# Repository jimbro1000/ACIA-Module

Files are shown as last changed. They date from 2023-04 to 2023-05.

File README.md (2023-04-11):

# HD6309SBC ACIA MODULE #

This design provides a standard RS232 capability to the
HD6309SBC board. Available baud rates range from 50 to
115200.

## Interface ##

The board utilises mapped IO at address #xx0C to interact
with the primary processor. The R65C51 uart provides four
registers starting at this address.

The value of xx depends on the "mapped memory" signal line,
by default this is $FF00.

## Notes ##

The intended clock speed of the main SBC board is just over
3MHz which exceeds the limits of the original R65C51.
A slower clock speed would facilitate the use of the Rockwell
made components but it is highly recommended to use the WDC
version which will operate at much higher clock frequencies
(higher than the main clock can supply)

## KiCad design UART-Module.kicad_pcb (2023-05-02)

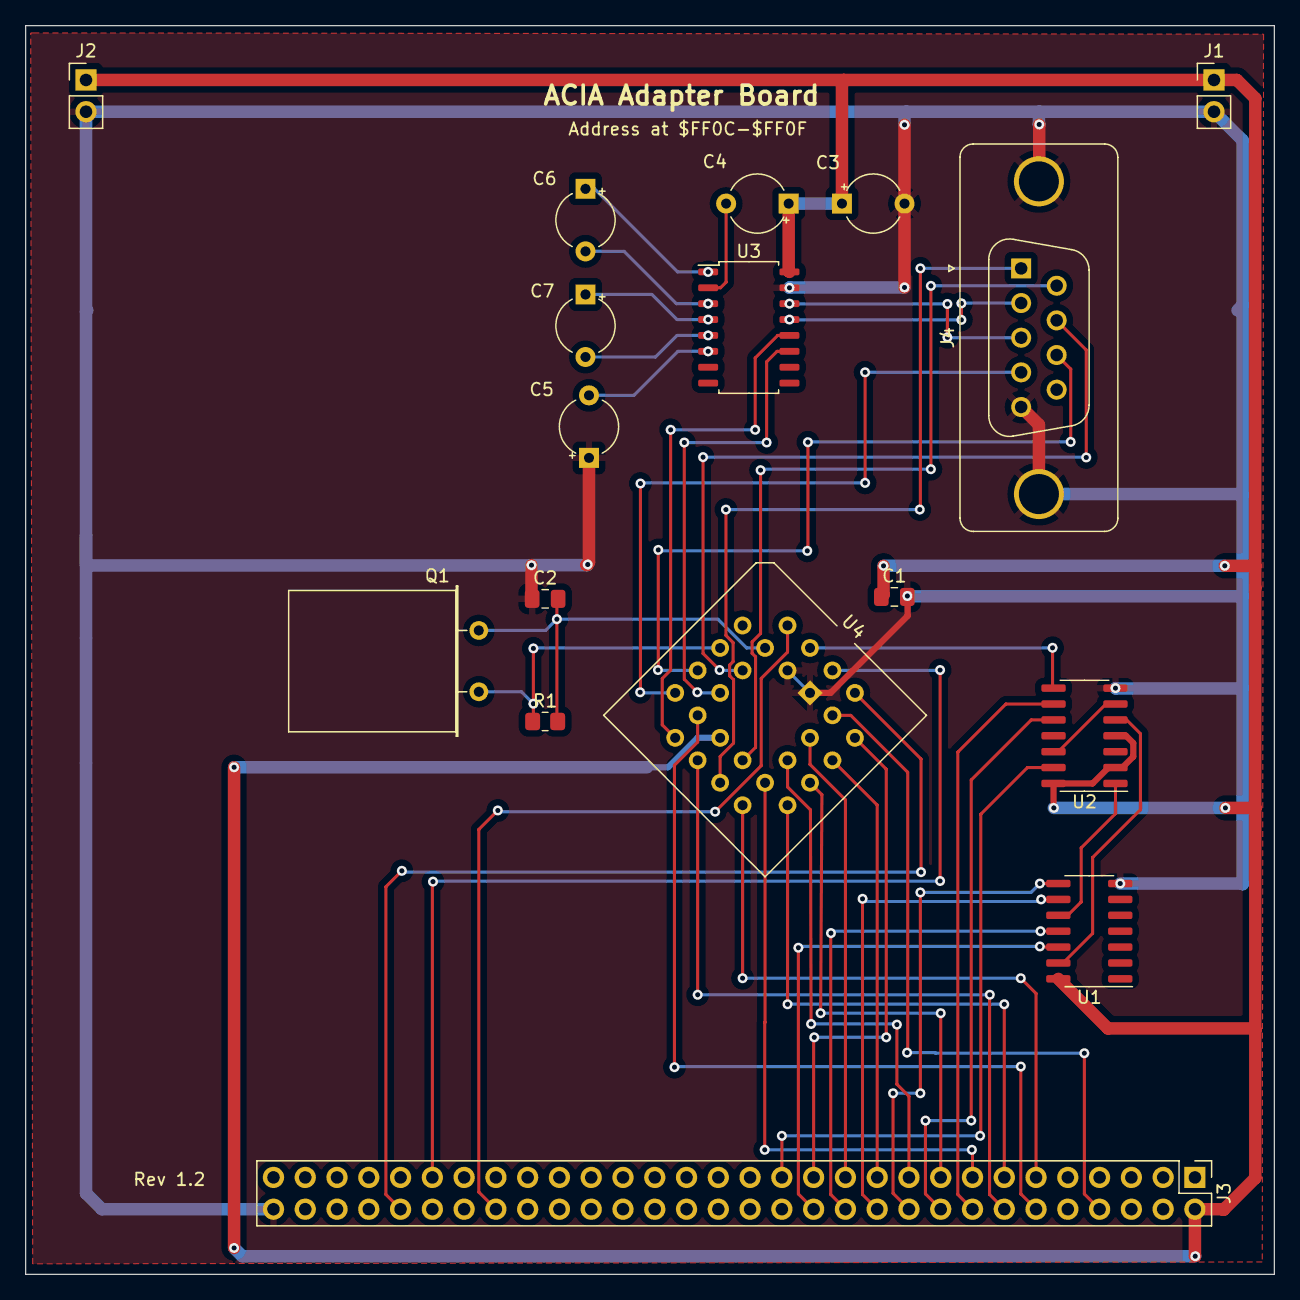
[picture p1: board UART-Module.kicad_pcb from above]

Board: 2 copper layers, 99.8 x 99.8 mm, 17 parts (0 on the bottom side), 44 nets.

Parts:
C1: 1uF; C_0805_2012Metric_Pad1.18x1.45mm_HandSolder
C2: 30pF; C_0805_2012Metric_Pad1.18x1.45mm_HandSolder
C3, C4, C5, C6, C7: 0.1uF; CP_Radial_Tantal_D4.5mm_P5.00mm
J1, J2: Conn_01x02_Male; PinHeader_1x02_P2.54mm_Vertical
J3: Conn_02x30_Odd_Even; PinHeader_2x30_P2.54mm_Vertical
J4: DE9_Receptacle_MountingHoles; DSUB-9_Female_Vertical_P2.77x2.84mm_MountingHoles
Q1: 1.8432; Crystal_HC18-U_Horizontal
R1: 1M; R_0805_2012Metric_Pad1.20x1.40mm_HandSolder
U1: 74HC02; SO-14_3.9x8.65mm_P1.27mm
U2: 74HC21; SO-14_3.9x8.65mm_P1.27mm
U3: MAX232ID; SOIC-16_4.55x10.3mm_P1.27mm
U4: R65C51; PLCC-28_THT-Socket

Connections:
+5V: C1.1, C3.1, C4.1, J1.1, J2.1, J3.2, U1.14 (VCC), U2.2, U2.4, U2.14 (VCC), U3.16 (VCC), U4.15 (VCC)
A0: J3.12, U4.13 (RS0)
A1: J3.14, U4.14 (RS1)
A2: J3.16, U2.9
A3: J3.18, U2.10
A4: J3.20, U1.8
A5: J3.22, U1.9
A6: J3.24, U1.11
A7: J3.26, U1.12
CS0: U2.8, U4.2 (CS0)
D0: J3.11, U4.18 (D0)
D1: J3.13, U4.19 (D1)
D2: J3.15, U4.20 (D2)
D3: J3.17, U4.21 (D3)
D4: J3.19, U4.22 (D4)
D5: J3.21, U4.23 (D5)
D6: J3.23, U4.24 (D6)
D7: J3.25, U4.25 (D7)
E: J3.8, U4.27 (phi2)
GND: C1.2, C2.1, C3.2, C5.1, J1.2, J2.2, J3.60, J4.0 (PAD), J4.5, U1.7 (GND), U2.7 (GND), U3.15 (GND), U4.1 (VSS), U4.3 (~CS1)
MAPPED_MEM: J3.27, U2.13
unnamed: U1.10, U2.1
unnamed: U1.13, U2.5
unnamed: U2.6, U2.12
unnamed: C6.1, U3.1 (C1+)
unnamed: C6.2, U3.3 (C1-)
unnamed: C7.1, U3.4 (C2+)
unnamed: C7.2, U3.5 (C2-)
unnamed: C4.2, U3.2 (VS+)
unnamed: C5.2, U3.6 (VS-)
RxD: U3.12 (R1OUT), U4.12 (RxD)
RxDv: J4.2, U3.13 (R1IN)
R/~W: J3.49, U4.28 (R/~W)
TxD: U3.11 (T1IN), U4.10 (TxD)
TxDv: J4.3, U3.14 (T1OUT)
XTLI: C2.2, Q1.1, R1.2, U4.6 (XTLI)
XTLO: Q1.2, R1.1, U4.7 (XTLO)
~CTS: J4.8, U4.9 (~CTS)
~DCD: J4.1, U4.16 (~DCD)
~DSR: J4.6, U4.17 (~DSR)
~DTR: J4.4, U4.11 (~DTR)
~IRQ: J3.52, U4.26 (~IRQ)
~RESET: J3.46, U4.4 (~RESET)
~RTS: J4.7, U4.8 (~RTS)

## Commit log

2023-04-10 revise components
    [UART-Module.kicad_pcb, UART-Module.kicad_sch]
2023-04-11 complete traces
    [UART-Module.kicad_pcb, UART-Module.kicad_sch]
2023-04-11 fix chip select
    [UART-Module.kicad_pcb, UART-Module.kicad_sch, addressing.kicad_sch]
2023-04-21 add max232 for correct serial voltages
    [UART-Module.kicad_pcb, UART-Module.kicad_sch]
2023-05-02 fix footprint for U3
    [UART-Module.kicad_pcb, UART-Module.kicad_sch]
